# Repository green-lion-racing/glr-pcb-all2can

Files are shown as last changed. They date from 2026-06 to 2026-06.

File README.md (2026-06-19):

# glr-pcb-all2can

This is a KiCad PCB repository for the [All2Can](https://github.com/green-lion-racing/glr-all2can) software.

<div align="center">
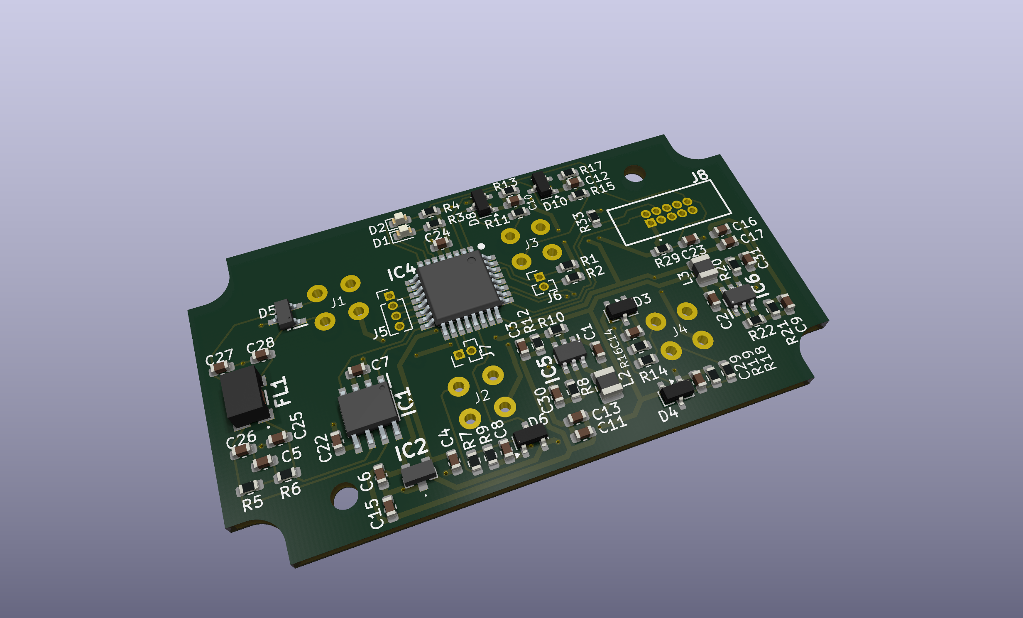
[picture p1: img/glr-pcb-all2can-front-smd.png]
  
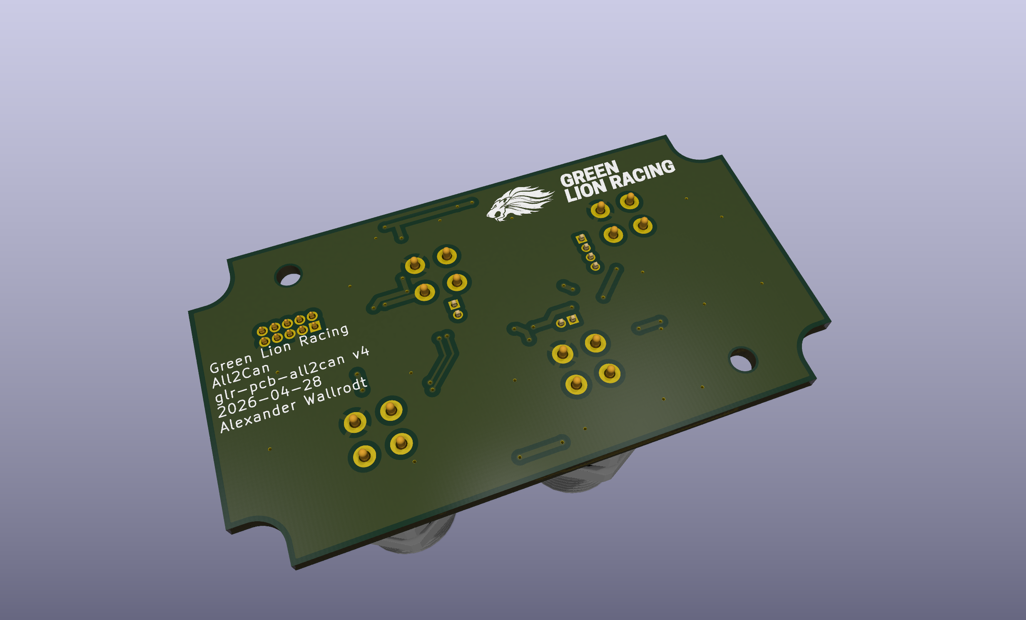
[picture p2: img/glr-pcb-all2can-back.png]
  
</div>
<div align="center">
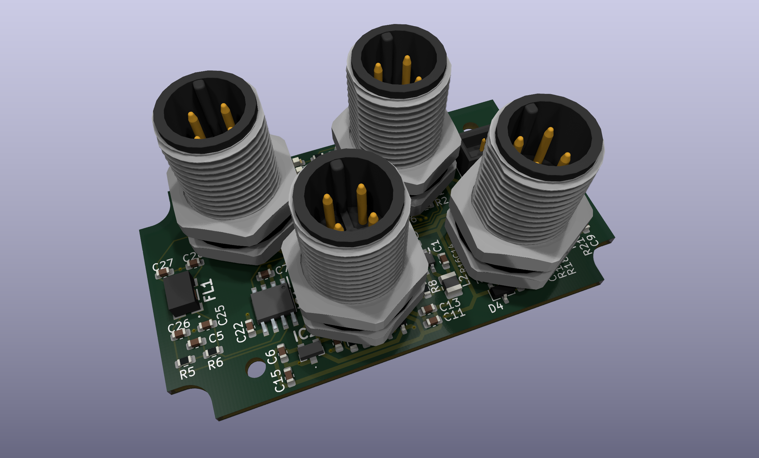
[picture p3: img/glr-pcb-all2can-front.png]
  
</div>

## Overview

This PCB is intended to collect sensor data and provide that to can.

The connector is D-Sub 15-pin male.  
It supports a 24V power supply voltage.  
One CAN (up to 5 MB/s) connection.  
Uses a `STMSTM32C092KCT6` microcontroller (250kbytes Flash 36kbytes Ram).  
It also preserves space for an 6-axis IMU `LSM6DSV16BXTR`.  

There are 7 analog/digital inputs (input voltage level is configurable by a voltage divider).  
And 4 digital outputs (5V level).

Provides headers for SPI, I2C, UART.

## History

This PCB is actually the fourthst generation of this type used for our team.

1. [Frist version](https://circuitmaker.com/Projects/Details/Pat-Her/All2Can-V01) in CircuitMaker.  
   By [PatHer777](https://github.com/PatHer777).

2. [Second version](https://circuitmaker.com/Projects/Details/Jannis-Dohm/All2Can) also in CircuitMaker with some changes.  
   By Jannis Dohm.

3. Third in Fusion 360, with new PCB design.  
   By Alexander Wallrodt.

4. Now [fourth version](https://github.com/green-lion-racing/glr-pcb-all2can) in KiCad, with some changes to schematic and smaller PCB.  
   By Alexander Wallrodt.

## Used parts

Exported from KiCad BOM. View there for more details.

| DigiKey | WuerthElektronik | Reference | Qty | Value | Footprint |
|---|---|---|-----|---|---|
| 311-100KHRCT-ND | | R33 | 1 | 100k | Resistor_SMD:R_0603_1608Metric |
| RMCF0603FT115KCT-ND | | R12 | 1 | 115k | Resistor_SMD:R_0603_1608Metric |
| 311-22.1KHRCT-ND | | R10,R22 | 2 | 22.1k | Resistor_SMD:R_0603_1608Metric |
| | | R9,R13,R16,R17,R19,R21 | 6 | ~ | Resistor_SMD:R_0603_1608Metric |
| P30KDBCT-ND | | R7,R11,R14,R15,R18 | 5 | 30k | Resistor_SMD:R_0603_1608Metric |
| 541-60.4HCT-ND | | R5,R6 | 2 | 60 | Resistor_SMD:R_0603_1608Metric |
| P120DBCT-ND | | R3,R4 | 2 | 120 | Resistor_SMD:R_0603_1608Metric |
| 311-10.0KHRCT-ND | | R1,R2,R8,R20,R29 | 5 | 10k | Resistor_SMD:R_0603_1608Metric |
| | | L3 | 1 | ~ | Inductor_SMD:L_1008_2520Metric |
| 732-74479889310CT-ND | 74479889310 | L2 | 1 | 10u | Inductor_SMD:L_1008_2520Metric |
| 732-62701021621-ND | 62701021621 | J8 | 1 | 62701021621 | SamacSys_Parts:62701021621 |
| 732-643250100304-ND | 643250100304 | J1,J2,J3,J4 | 4 | Conn_02x02_Counter_Clockwise_Shielded | GLR_KiCad_Library:M12A-04P |
| 31-AP64060QWU-7CT-ND | | IC5,IC6 | 2 | AP64060WU-7 | SamacSys_Parts:SOT95P280X100-6N |
| 497-STM32C092KCT6-ND | | IC4 | 1 | STM32C092KCT6 | SamacSys_Parts:QFP80P900X900X160-32N |
| ZMR330FCT-ND | | IC2 | 1 | ZMR330FTA | SamacSys_Parts:ZMR330FTA |
| ATA6561-GAQW-NCT-ND | | IC1 | 1 | ATA6561-GAQW-N | SamacSys_Parts:SOIC127P600X175-8N |
| 732-7290-1-ND | 744235510 | FL1 | 1 | Choke | SamacSys_Parts:744235510 |
| 497-15333-1-ND | | D5 | 1 | ESDCAN01-2BLY | SamacSys_Parts:SOT95P255X125-3N |
| 4878-BAT54SCT-ND | | D3,D4,D6,D8,D10 | 5 | BAT54S | Package_TO_SOT_SMD:SOT-23 |
| 160-1436-1-ND,160-1447-1-ND | | D1,D2 | 2 | LED | LED_SMD:LED_0603_1608Metric |
| 1276-1040-1-ND | | C30,C31 | 2 | 2u2 | Capacitor_SMD:C_0603_1608Metric |
| 490-1427-1-ND | | C25,C26,C27,C28 | 4 | 100p | Capacitor_SMD:C_0603_1608Metric |
| 399-C0603C105K4RACTUCT-ND | | C11,C16,C24 | 3 | 1u | Capacitor_SMD:C_0603_1608Metric |
| 1292-0603X106M100CT-ND | | C4,C6 | 2 | 10u | Capacitor_SMD:C_0603_1608Metric |
| 399-C0603C104K3RACTUCT-ND | | C1,C2,C3,C5,C7,C8,C9,C10,C12,C13,C14,C15,C17,C22,C23,C29 | 16  | 100n | Capacitor_SMD:C_0603_1608Metric |

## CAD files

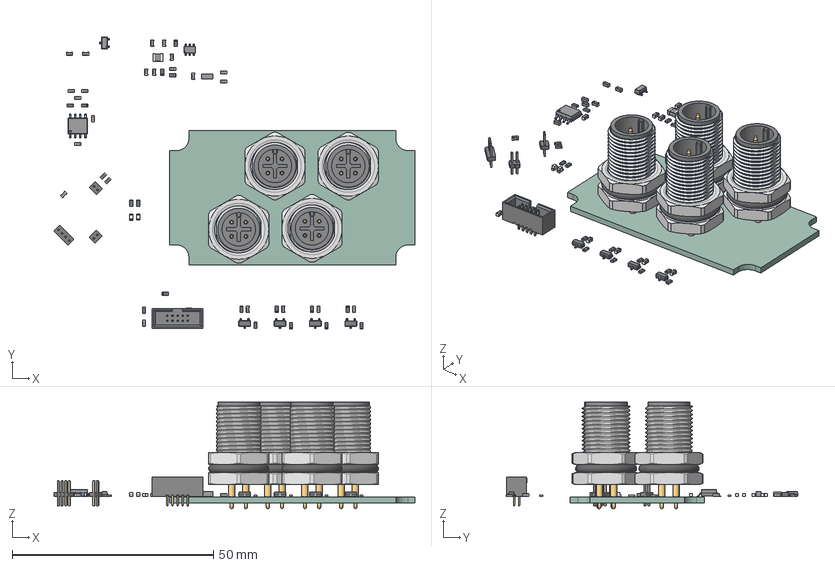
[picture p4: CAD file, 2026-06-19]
glr-pcb-all2can.step
89.8 x 72.6 x 26.5 mm
PinHeader_1x02_P1.27mm_Vertical x 2
C_0603_1608Metric x 22
LED_0603_1608Metric x 2
R_0603_1608Metric x 19
PinHeader_1x04_P1.27mm_Vertical
SOT-23 x 4
Pins
PinsArrayL
FilletPinR
L_1008_2520Metric
6431501003xx_Housing x 4
643150100604_insulator x 4
643xx01003xx_Seal_outer x 4
643xx01003xx_Nut x 4
6432501006xx_pin x 16
6432501003xx_Glue x 4
6270xx21621_Pin x 10
PinsArrayLR
AP64060WU-7
glr-pcb-all2can_PCB

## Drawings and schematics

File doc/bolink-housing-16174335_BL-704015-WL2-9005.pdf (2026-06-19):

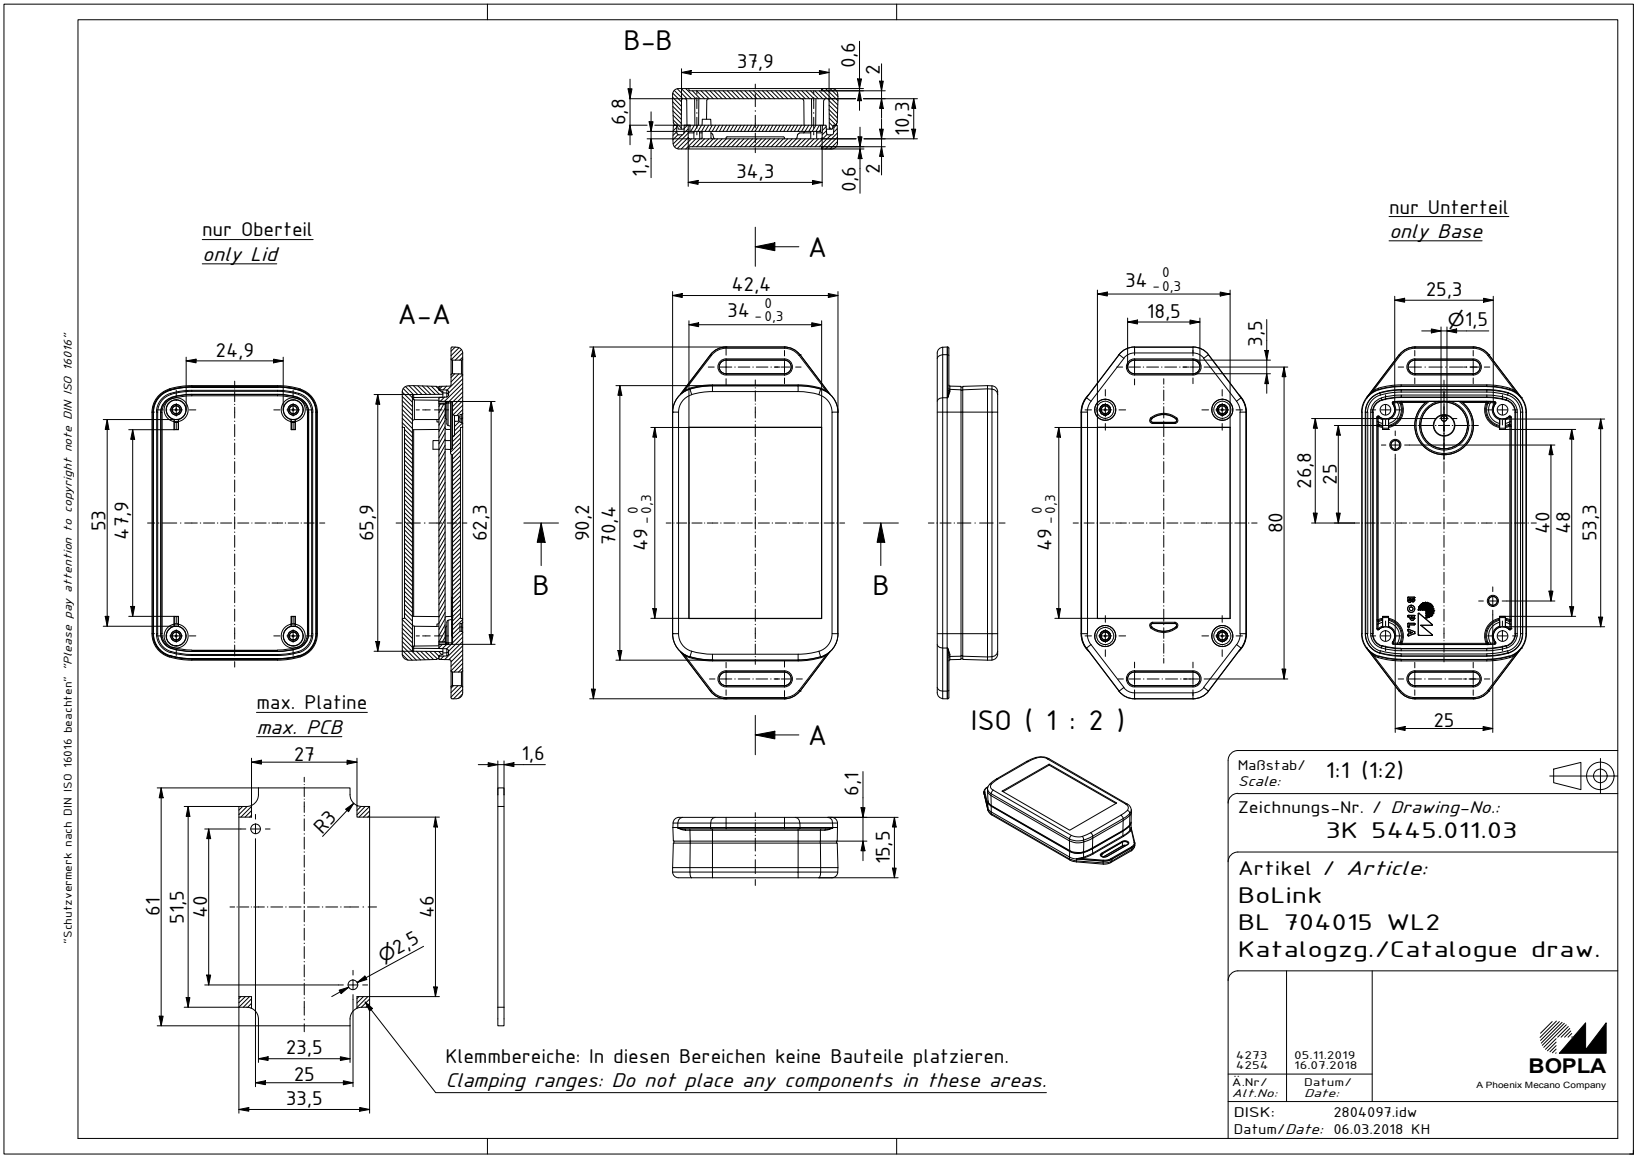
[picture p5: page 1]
ISO ( 1 : 2 ); nur Oberteil only Lid; nur Unterteil only Base; max. Platine max. PCB

yright note DIN IS

"Schutzvermerk nach DIN ISO 16016 beachten" "Please pay attention to cop

Mastab/
Scale:
Zeichnungs-Nr. / Drawing-No.:

Artikel / Article:
BoLink
Katalogzg./Catalogue draw.

Klemmbereiche: In diesen Bereichen keine Bauteile platzieren.
Clamping ranges: Do not place any components in these areas.

A Phoenix Mecano Company

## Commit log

2025-11-15 add first can transcievers
    update to glr-pcb-all2can references
    [can-bus.kicad_sch, glr-pcb-all2can.kicad_pcb, glr-pcb-all2can.kicad_sch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]
2025-11-15 add 3d viewports
    exclude mounting holes from schematic
    [glr-pcb-all2can.kicad_pcb]
2025-11-25 add main chip stm32f303k8t6
    add two status leds
    add debug/flash pins
    connect first pins
    remove second canbus
    [can-bus.kicad_sch, glr-pcb-all2can.kicad_pcb, glr-pcb-all2can.kicad_sch]
2025-12-03 add voltage converters by würth elektronik
    add würth library
    [glr-pcb-all2can.kicad_sch]
2025-12-10 add in- and outputs
    [can-bus.kicad_sch, glr-pcb-all2can.kicad_pcb, glr-pcb-all2can.kicad_sch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]
2025-12-13 change voltage regulators
    change can transciever
    add more useful parts to can setup
    [can-bus.kicad_sch, glr-pcb-all2can.kicad_pcb, glr-pcb-all2can.kicad_sch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]
2026-01-03 switch to ic STM32C092KCT6
    use more labels
    add optional i2c and uart
    [can-bus.kicad_sch, glr-pcb-all2can.kicad_sch]
2026-01-03 added 6 axis imu LSM6DSV16BXTR
    fixed link in in input filter
    removed optional i2c
    add not connected elements to ic
    [can-bus.kicad_sch, glr-pcb-all2can.kicad_sch, imu.kicad_sch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]
2026-01-03 group parts on pcb
    replace footprints
    update can setup
    [can-bus.kicad_sch, glr-pcb-all2can.kicad_pcb, glr-pcb-all2can.kicad_sch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]
2026-01-07 fix i2c pull up
    [glr-pcb-all2can.kicad_sch, imu.kicad_sch]
2026-01-07 change swd header
    [glr-pcb-all2can.kicad_pcb, glr-pcb-all2can.kicad_sch]
2026-01-07 reorder more
    move pullup i2c in schematic
    make power passing routes thicker
    [glr-pcb-all2can.kicad_pcb, glr-pcb-all2can.kicad_sch, imu.kicad_sch]
2026-01-07 almost route everything
    [glr-pcb-all2can.kicad_pcb]
2026-01-10 add missing pull down resistor for swd
    [glr-pcb-all2can.kicad_pcb, glr-pcb-all2can.kicad_sch]
2026-01-10 finish routing everything
    [glr-pcb-all2can.kicad_pcb]
2026-01-10 remove inner layers
    [glr-pcb-all2can.kicad_pcb]
2026-01-10 add my self :)
    [glr-pcb-all2can.kicad_pcb]
2026-04-04 massive overhaul of pcb
    * replace sub-d with 4x m12a 4pin circular connector
    * fit board to bopla bolink case
    * restructure entire board
    * add second main voltage converter for powering input devices
    * reduce inputs to 5
    * remove 6 axis imu
    * remove outputs
    * remove mounting holes
    [can-bus.kicad_sch, glr-pcb-all2can.kicad_pcb, glr-pcb-all2can.kicad_sch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]
2026-04-18 update to kicad 10
    [can-bus.kicad_sch, glr-pcb-all2can.kicad_pcb, glr-pcb-all2can.kicad_sch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]
2026-04-18 change esd protection to +3v3 reference voltage
    [input-filter.kicad_sch]
2026-04-18 update buck converters
    [glr-pcb-all2can.kicad_pcb, glr-pcb-all2can.kicad_sch]
2026-04-28 routing mostly done
    * missed that there need to be holes in bopla housing
    * add stm32 chip datasheet
    * remove unused würth library
    * change pins on chip of sensor data input
    [glr-pcb-all2can.kicad_pcb, glr-pcb-all2can.kicad_sch]
2026-04-28 move parts out of holes
    * check drc
    * fix silk texts
    [glr-pcb-all2can.kicad_pcb]
2026-04-28 add housing datasheet
2026-05-15 setup as aisler project
    [glr-pcb-all2can.kicad_pcb]
2026-05-15 update to merged glr kicad library
    [glr-pcb-all2can.kicad_sch]
2026-05-15 really update glr kicad library fr fr
2026-05-15 increment to version 5
    [glr-pcb-all2can.kicad_pcb, glr-pcb-all2can.kicad_sch]
2026-06-03 add digikey/wuerth part numbers
    * update README.md part list
    [can-bus.kicad_sch, glr-pcb-all2can.kicad_sch, input-filter.kicad_sch]
